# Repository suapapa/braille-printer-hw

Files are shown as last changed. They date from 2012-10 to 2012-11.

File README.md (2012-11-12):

# Hardware for Braille Label Printer

- sch : schemetic(.sch) and artwork(.brd) made by EagleCad-6
- cad : drawing for laser cut acrylic case made by Librecad
- arduino : arduino sketch

# License

The sch, cad and arduino sketch follow GNU-GPL.

    Copyright (c) 2012 Homin Lee <homin.lee@suapapa.net>. All right reserved.

    This is free software; you can redistribute it and/or
    modify it under the terms of the GNU Lesser General Public
    License as published by the Free Software Foundation; either
    version 2.1 of the License, or (at your option) any later version.

    This library is distributed in the hope that it will be useful,
    but WITHOUT ANY WARRANTY; without even the implied warranty of
    MERCHANTABILITY or FITNESS FOR A PARTICULAR PURPOSE.  See the GNU
    Lesser General Public License for more details.

    You should have received a copy of the GNU Lesser General Public
    License along with this library; if not, write to the Free Software
    Foundation, Inc., 51 Franklin St, Fifth Floor, Boston, MA  02110-1301  USA

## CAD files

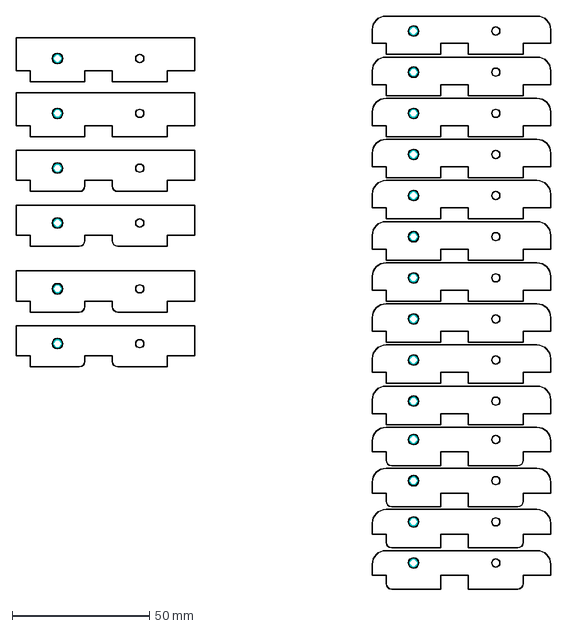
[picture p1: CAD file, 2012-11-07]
cad/braille-printer-acrilcase_1t.dxf
194.9 x 209.0 mm

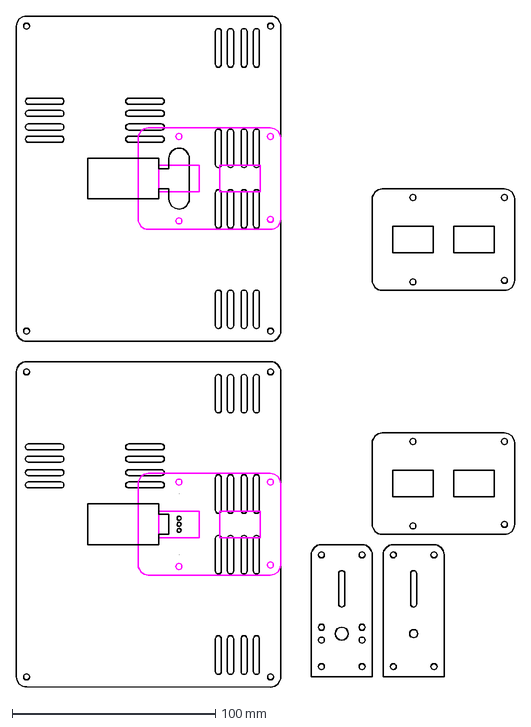
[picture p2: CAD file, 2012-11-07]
cad/braille-printer-acrilcase_5t.dxf
245.0 x 330.0 mm

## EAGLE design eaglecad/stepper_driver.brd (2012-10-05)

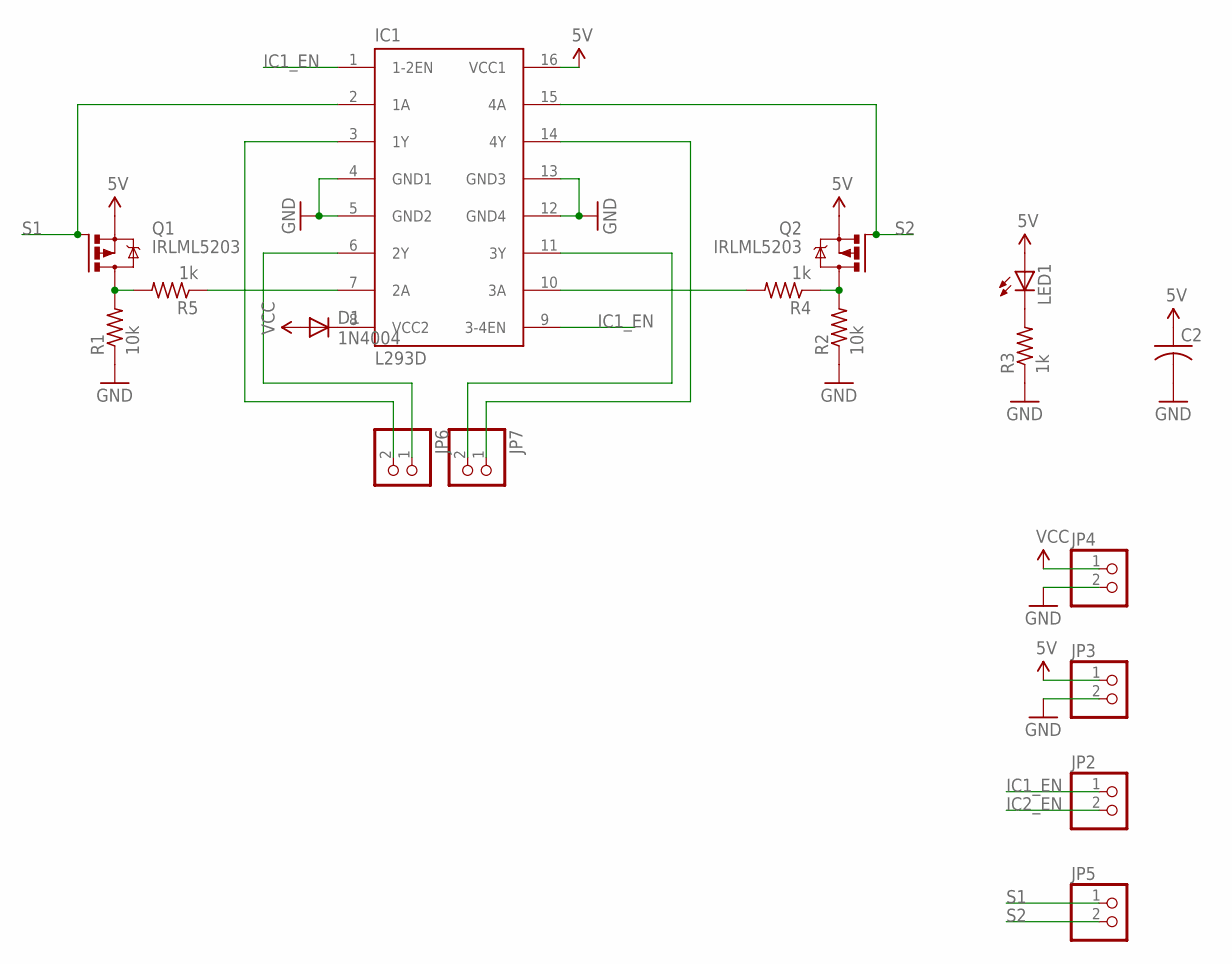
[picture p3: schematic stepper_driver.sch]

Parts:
C2: C-USC1206; C1206
D1: 1N4004; DO41-10
IC1: L293D; DIL16
JP2, JP3, JP4, JP5, JP6, JP7: PINHD-1X2; 1X02
LED1: LED5MM
Q1, Q2: IRLML5203; MICRO3
R1, R2: 10k; 0207/10
R3, R4, R5: 1k; 0207/10

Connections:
5V: C2.1, IC1.16 (VCC1), JP3.1, LED1.A, Q1.2 (S), Q2.2 (S)
GND: C2.2, IC1.4 (GND1), IC1.5 (GND2), IC1.12 (GND4), IC1.13 (GND3), JP3.2, JP4.2, R1.1, R2.1, R3.1
IC1_EN: IC1.1 (1-2EN), IC1.9 (3-4EN), JP2.1
IC2_EN: JP2.2
unnamed: IC1.3 (1Y), JP6.2
unnamed: IC1.6 (2Y), JP6.1
unnamed: IC1.11 (3Y), JP7.2
unnamed: IC1.14 (4Y), JP7.1
unnamed: IC1.7 (2A), R5.1
unnamed: D1.C, IC1.8 (VCC2)
unnamed: IC1.10 (3A), R4.2
unnamed: LED1.K (C), R3.2
unnamed: Q1.3 (D), R1.2, R5.2
unnamed: Q2.3 (D), R2.2, R4.1
S1: IC1.2 (1A), JP5.1, Q1.1 (G)
S2: IC1.15 (4A), JP5.2, Q2.1 (G)
VCC: D1.A, JP4.1

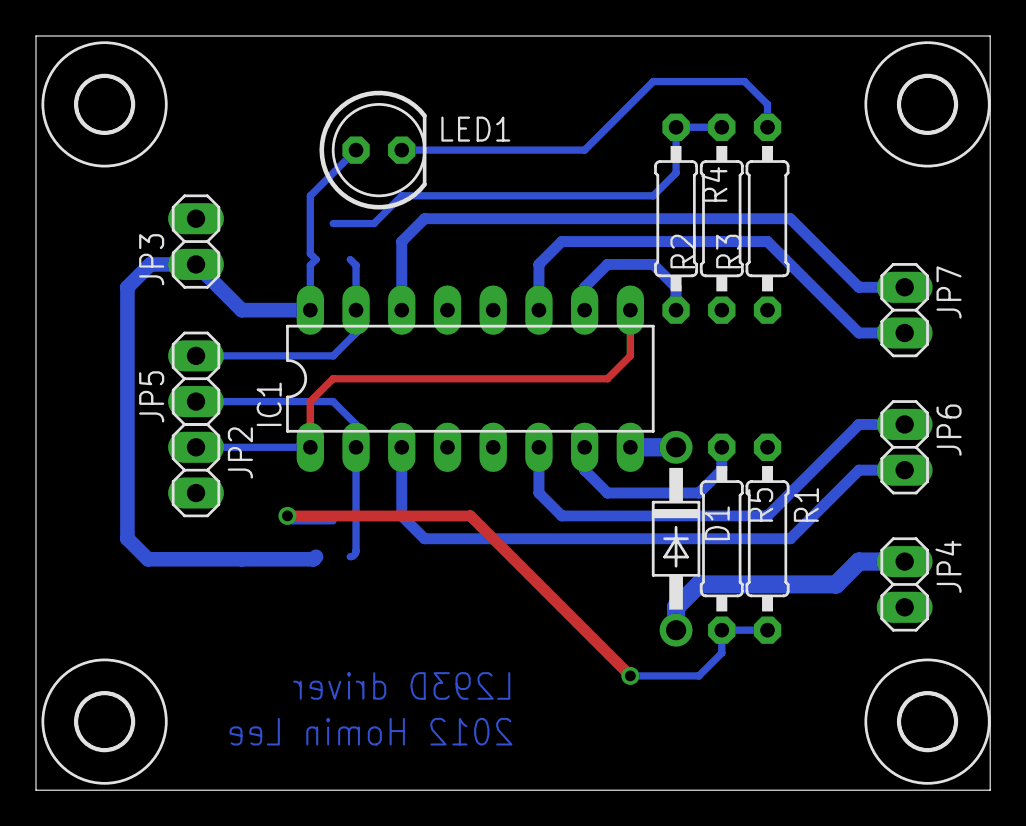
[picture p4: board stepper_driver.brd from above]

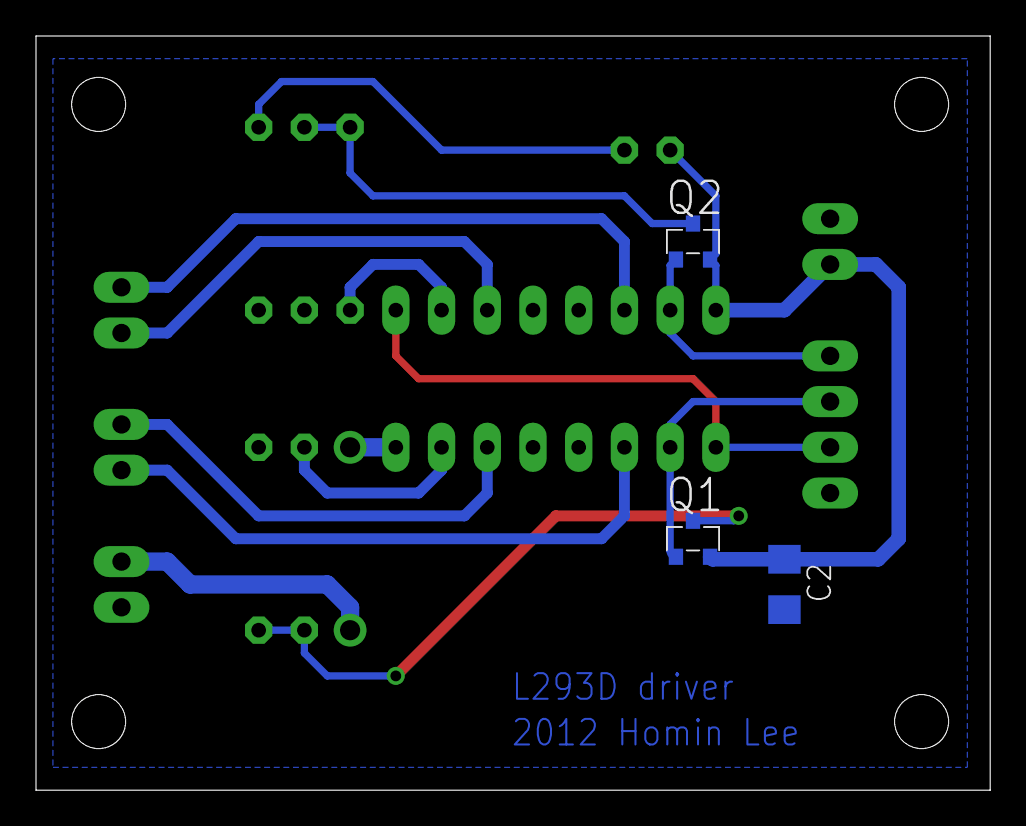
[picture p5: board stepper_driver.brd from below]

Board: 2 copper layers, 53.0 x 41.9 mm, 21 parts (3 on the bottom side), 16 nets.

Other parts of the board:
U$6, U$7, U$8, U$9: 3,0

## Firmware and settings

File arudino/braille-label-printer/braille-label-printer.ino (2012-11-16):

/*
  braille-label-printer.ino - Arduino sketch for Braille Label Printer
  Copyright (c) 2012 Homin Lee <homin.lee@suapapa.net>. All right reserved.

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
  You should have received a copy of the GNU Lesser General Public
  License along with this library; if not, write to the Free Software
  Foundation, Inc., 51 Franklin St, Fifth Floor, Boston, MA  02110-1301  USA
*/

// #define FACTORY_TEST

#define PIN_LED 13

// pins for LCD
#define PIN_LCD_RS 9
#define PIN_LCD_EN 8
#define PIN_LCD_D4 16
#define PIN_LCD_D5 17
#define PIN_LCD_D6 18
#define PIN_LCD_D7 19
#define PIN_LCD_BL 11

// pins for stepper
#define PIN_STP_1 6
#define PIN_STP_2 7
#define PIN_STP_3 10
#define PIN_STP_4 12

// pins for servos
#define PIN_SRV_1 5
#define PIN_SRV_2 2
#define PIN_SRV_3 4

/*---------------------------------------------------------------------------*/

#include <LiquidCrystal.h>

LiquidCrystal lcd(PIN_LCD_RS, PIN_LCD_EN,
    PIN_LCD_D4, PIN_LCD_D5, PIN_LCD_D6, PIN_LCD_D7);

void _displayBraille(int n, int t, unsigned char ch)
{
  lcd.clear();
  lcd.setCursor(0, 0);
  lcd.print('[');
  lcd.print(n);
  lcd.print('/');
  lcd.print(t);
  lcd.print("] ");

  for (int i = 0; i < 6; i++) {
    if ((ch >> i) & 1)
      lcd.print(i + 1);
  }
}

static int lastBL = 0;
static int _lcdBacklight(int v)
{
  if (lastBL == v)
    return 0;

  int delayed = 0;

  if (lastBL > v) {
    for (int i = lastBL; i != v; i--) {
      analogWrite(PIN_LCD_BL, i);
      delay(10);
      delayed += 10;
    }
  } else {
    for (int i = lastBL; i != v; i++) {
      analogWrite(PIN_LCD_BL, i);
      delay(10);
      delayed += 10;
    }
  }
  lastBL = v;

  return delayed;
}

static void _initLCD(void)
{
  lcd.begin(16, 2);
  lcd.clear();
  lcd.setCursor(2, 0);
  lcd.print("Braille Label");
  lcd.setCursor(5, 1);
  lcd.print("Printer");
  _lcdBacklight(200);
}

/*---------------------------------------------------------------------------*/

#include <Stepper.h>

Stepper stepperFeed(200, PIN_STP_3, PIN_STP_4, PIN_STP_2, PIN_STP_1);

static void _turnOffStepper(void)
{
  digitalWrite(PIN_STP_1, LOW);
  digitalWrite(PIN_STP_2, LOW);
  digitalWrite(PIN_STP_3, LOW);
  digitalWrite(PIN_STP_4, LOW);
}

static void _feed(int step)
{
  stepperFeed.step(step);
  _turnOffStepper();
}

static void _initStepper(void)
{
  stepperFeed.setSpeed(30);
  _turnOffStepper();
}

/*---------------------------------------------------------------------------*/

#include <Servo.h>

#define SECS 1000

Servo servoPunch[3];

static void _press(int idx)
{
  Servo *servo;
  int press[3] = {30, 0, 180};

  switch(idx) {
    case 1: case 2: case 3:
      digitalWrite(PIN_LED, HIGH);
      servo = &servoPunch[idx - 1];
      servo->write(press[idx - 1]);
      break;
  }
}

static void _release(int idx)
{
  Servo *servo;
  int release[3] = {120, 120, 60};

  switch(idx) {
    case 1: case 2: case 3:
      digitalWrite(PIN_LED, LOW);
      servo = &servoPunch[idx - 1];
      servo->write(release[idx - 1]);
      break;
  }
}

static void _pressAndRelease(int idx)
{
  switch(idx) {
    case 1: case 2: case 3:
      lcd.setCursor(0, 1);
      lcd.print("Puncing ");
      lcd.print(idx);
      lcd.print("...");

      _press(idx); delay(2 * SECS);
      _release(idx); delay(0.5 * SECS);
      break;

    default:
      _release(1);
      _release(2);
      _release(3);
      delay(1 * SECS);
      break;
  }
}

static void _initPunchs(void)
{
  servoPunch[0].attach(PIN_SRV_1);
  servoPunch[1].attach(PIN_SRV_2);
  servoPunch[2].attach(PIN_SRV_3);
  _pressAndRelease(0);
}

static void _punchBraille(unsigned char ch)
{
  _feed(10);

  if ((ch >> 0) & 1)
    _pressAndRelease(1);
  if ((ch >> 1) & 1)
    _pressAndRelease(2);
  if ((ch >> 2) & 1)
    _pressAndRelease(3);
  _feed(5);

  if ((ch >> 3) & 1)
    _pressAndRelease(1);
  if ((ch >> 4) & 1)
    _pressAndRelease(2);
  if ((ch >> 5) & 1)
    _pressAndRelease(3);
}

/*---------------------------------------------------------------------------*/

#define SERIAL_SPEED 9600

void setup(void)
{
  Serial.begin(SERIAL_SPEED);

  pinMode(PIN_LED, OUTPUT);
  digitalWrite(PIN_LED, HIGH);

  _initLCD();
  _initPunchs();
  _initStepper();
  _feed(300);
  _pressAndRelease(0);
}

void loop(void)
{
  digitalWrite(PIN_LED, LOW);
  // Protocol begin with "####"
  if (Serial.available() > 4 &&
      Serial.read() == '#' && Serial.read() == '#' &&
      Serial.read() == '#' && Serial.read() == '#') {
    unsigned char strSize = Serial.read();
    lcd.clear();
    lcd.setCursor(0,0);
#ifdef FACTORY_TEST
    delay(strSize * 1000 / (SERIAL_SPEED / 8) + 10);
    unsigned char testFunction = Serial.read();
    switch (testFunction) {
      case 'P':
        _press(Serial.read() - '0');
        break;
      case 'R':
        _release(Serial.read() - '0');
        break;
      case 'F':
        _feed(100);
        break;
    }
#else
    lcd.print("RCVing ");
    lcd.print(strSize);
    lcd.print(" chars...");
    _lcdBacklight(200);
    delay(strSize * 1000 / (SERIAL_SPEED / 8) + 10);
    for (int i = 0; i < strSize; i++) {
      unsigned char bch = Serial.read();
      _displayBraille(i+1, strSize, bch);
      _punchBraille(bch);
    }
#endif
    // Serial.print("OK");
  }
  lcd.clear();
  lcd.setCursor(0,0);
#ifdef FACTORY_TEST
  lcd.print("# FACTORY TEST #");
#else
  lcd.print("Wating...");
#endif

  if (0 == _lcdBacklight(100))
    delay(10);
}

/* vim: set sw=2 et: */

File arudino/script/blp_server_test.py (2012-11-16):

#!/usr/bin/python
# -*- coding: utf-8 -*-
 
# blp_server_test.py - Simple test for BLP server
#
# Copyright (C) 2012 Homin Lee <homin.lee@suapapa.net>
#
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
import socket
import sys
import os

sock = socket.socket(socket.AF_UNIX, socket.SOCK_DGRAM)
UDSPath = "/tmp/blp_uds"

if __name__ == "__main__":
    if len(sys.argv) != 2:
        print("usage: %s <message>"%sys.argv[0])
        exit(1)

    data = sys.argv[1]
    packet = "####%s%s"%(chr(len(data)), data)
    n = sock.sendto(packet, UDSPath)
    if (n != len(packet)):
       print("somthing wrong!")
       exit(1)

    exit(0)

# vim: et sw=4 fenc=utf-8:

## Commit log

2012-09-28 Initial import of BraillePrinter HW
    [stepper_driver.brd, stepper_driver.sch]
2012-09-28 First draft artwork done
    [stepper_driver.brd]
2012-09-28 Polishing artwork
    [stepper_driver.brd, stepper_driver.sch]
2012-10-05 Fix to only for single L293D IC
    [stepper_driver.brd, stepper_driver.sch]
2012-10-06 cad: add blueprint for feeder
    [braille-printer-acrilcase.dxf]
2012-10-13 cad: split cad drawing to 1t and 5t. following it's t dimention
    [braille-printer-acrilcase.dxf, braille-printer-acrilcase_1t.dxf, braille-printer-acrilcase_5t.dxf]
2012-10-13 cad: fixed drawing
    [braille-printer-acrilcase_1t.dxf, braille-printer-acrilcase_5t.dxf]
2012-10-30 cad: fixed 5t acril
    [braille-printer-acrilcase_5t.dxf]
2012-10-30 cad: removed unused parts from acril 5t
    [braille-printer-acrilcase_5t.dxf]
2012-11-07 Rework laser cutting
    [braille-printer-acrilcase_1t.dxf, braille-printer-acrilcase_5t.dxf]
2012-11-07 cad: more fixes
    [braille-printer-acrilcase_1t.dxf]
2012-11-10 Testing serial and stepper
2012-11-10 arduino: fill up draft codes
2012-11-10 arduino: add script to test protocol
2012-11-12 arduino: add codes for servos
2012-11-12 arduino: add codes for lcd
2012-11-12 arduino: put it all together
2012-11-12 arduino: put all servos to release position after init servos
2012-11-12 arduino: clean up code
2012-11-12 Add files which made by arduino build to .gitignore
2012-11-12 moved eaglecad files to a directory, eaglecad
    [stepper_driver.brd, stepper_driver.sch]
2012-11-12 arduino: fix pinmaps
2012-11-12 arduino: fixed to use working gpio
    [braille-label-printer.ino]
2012-11-16 arduino: fix servo's pin and direction
    [braille-label-printer.ino]
2012-11-16 arduino: fix pinmap, trasition on backlight
    [braille-label-printer.ino]
2012-11-16 arduino: add scripts
    - blp_server.py: UDS server to Braille Label Printer
    - blp_server_test.py: simple script to test blp_server.py
    - blp_test.py: simple script to test Braille Label Printer via serial
2012-11-16 arduino: Fix not to send OK back
    Make it simple, simple, simple...
    [braille-label-printer.ino]

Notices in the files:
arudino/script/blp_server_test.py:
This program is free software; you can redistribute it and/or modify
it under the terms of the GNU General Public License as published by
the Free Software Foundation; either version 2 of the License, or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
